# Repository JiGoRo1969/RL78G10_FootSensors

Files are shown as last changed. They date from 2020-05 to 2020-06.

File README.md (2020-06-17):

# FootSensors with RL78/G10 software library (Rev.20200416)

This is a project to use Force Sensing Registors with RL78/G10
included with CS+ environment setting files provided by Renesas Electronics Corp.
So you can easily modify and add this codes with CS+ on Windows PC.
  
Let's enjoy it !

## Information for target board

RL78/G10 board "AE-R5F10Y47ASP" is provided by Akizukidenshi in Japan.
  
JPN : http://akizukidenshi.com/catalog/g/gK-09035/

## Installation

Import this project into CS+.

## Usage

The protocol stack is defined with an ICS3.5 provided by KONDO Kagaku.
ICS3.5 uses "Data=8bit, Stop=1bit, Parity=EVEN, baudrate=1.5Mbps."
You will get 4 sensor unit data when master MCU/MPU send 4 bytes data as follows :
|Command|SC|Address|Length|
|---|--|---|---|
|0xA0+ID|0x7F|0(fiexed)|4(fiexed)|
  
ID is defined as D_MY_ID in "cg_src/r_cg_userdefine.h".

## Current Support Peripherals

|Function Name | Pin Name | notes |
|:---|:---:|:---|
|Analog Input |P02/ANI1 | connecting to one of Force Sensing Registor with pulled up to 3.3V | 
|Analog Input |P03/ANI2 | connecting to one of Force Sensing Registor with pulled up to 3.3V | 
|Analog Input |P04/ANI3 | connecting to one of Force Sensing Registor with pulled up to 3.3V | 
|Analog Input |P05/ANI4 | connecting to one of Force Sensing Registor with pulled up to 3.3V | 
|UART I/F |P00/TxD0 | connecting to RxD of master MCU/MPU | 
|UART I/F |P01/RxD0 | connecting to TxD of master MCU/MPU | 
|X'tal |X1,X2 | mounted on board |
|OCD Debugger I/F |RESET, TOOL0 | connecting to DEBUGGER |
|Non Connections |P06, P07, P41 | |
  
You can refer CAD data with Eagle(.brd and .sch) to understand the circuit.
  
|File Name | purpose |
|:---:|:---:|
|RL78G10_FOOT_A2.brd| PCB pattern data for pressure sensors with R5F10Y47ASP|
|RL78G10_FOOT_A2.sch| circuit data |
|--------|-------|
|RL78G10_E1.brd| PCB pattern data connecting to E1/E2/E2Lite |
|RL78G10_E1.sch| circuit data |

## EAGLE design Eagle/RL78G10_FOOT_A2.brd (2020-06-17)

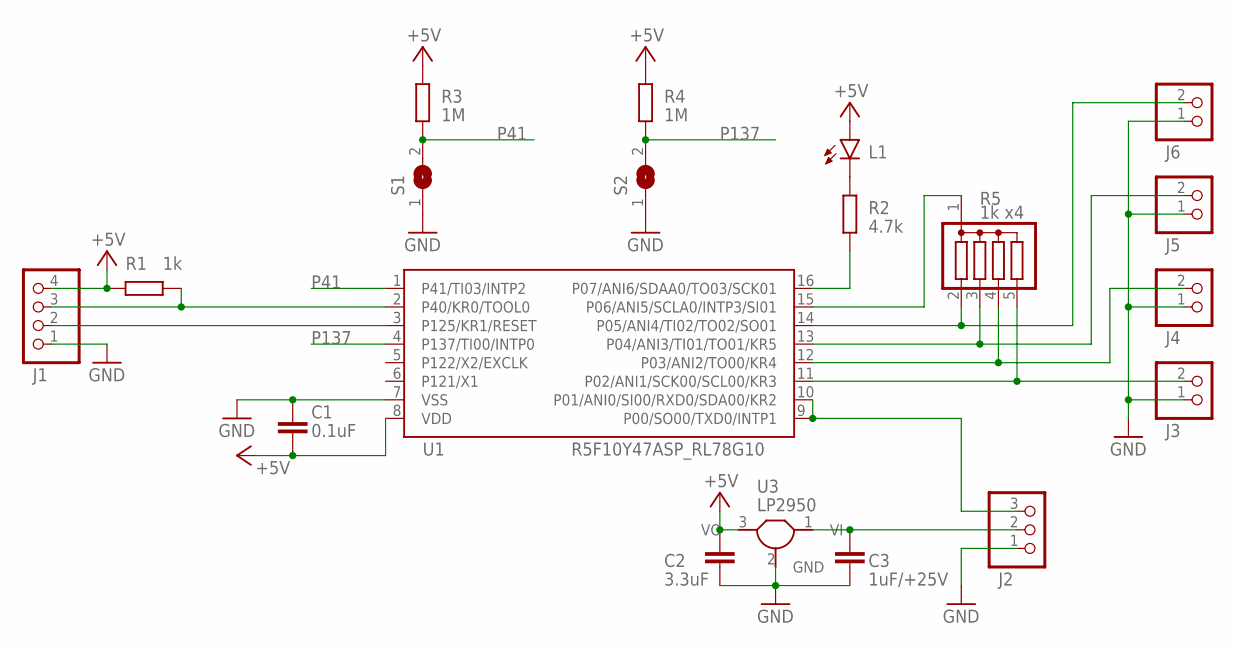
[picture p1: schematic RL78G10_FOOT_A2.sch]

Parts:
C1: 0.1uF; C0603
C2: 3.3uF; C0805
C3: 1uF/+25V; C0805
J1: PINHD_1X4; PINHD_1X04
J2: PINHD_1X3; PINHD_1X03
J3, J4, J5, J6: PINHD_1X2; PINHD_1X02
L1: LEDSML0603; SML0603
R1: 1k; R0603
R2: 4.7k; R0603
R3, R4: 1M; R0603
R5: 1k x4; SIL5
S1, S2: SJ-OMINI; SJ-O
U1: R5F10Y47ASP_RL78G10; SSOP16
U3: LP2950; TO92-

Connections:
+5V: C1.2, C2.1, J1.4, L1.A, R1.1, R3.1, R4.1, U1.8 (VDD), U3.3 (VO)
+V: C3.1, J2.2, U3.1 (VI)
ANI1: J3.2, R5.5, U1.11 (P02/ANI1/SCK00/SCL00/KR3)
ANI2: J4.2, R5.4, U1.12 (P03/ANI2/TO00/KR4)
ANI3: J5.2, R5.3, U1.13 (P04/ANI3/TI01/TO01/KR5)
ANI4: J6.2, R5.2, U1.14 (P05/ANI4/TI02/TO02/SO01)
GND: C1.1, C2.2, C3.2, J1.1, J2.1, J3.1, J4.1, J5.1, J6.1, S1.1, S2.1, U1.7 (VSS), U3.2 (GND)
LED: L1.C, R2.1
P06: R5.1, U1.15 (P06/ANI5/SCLA0/INTP3/SI01)
P41: R3.2, S1.2, U1.1 (P41/TI03/INTP2)
P137: R4.2, S2.2, U1.4 (P137/TI00/INTP0)
RESET: J1.2, U1.3 (P125/KR1/RESET)
SIG: J2.3, U1.9 (P00/SO00/TXD0/INTP1), U1.10 (P01/ANI0/SI00/RXD0/SDA00/KR2)
TO03: R2.2, U1.16 (P07/ANI6/SDAA0/TO03/SCK01)
TOOL0: J1.3, R1.2, U1.2 (P40/KR0/TOOL0)

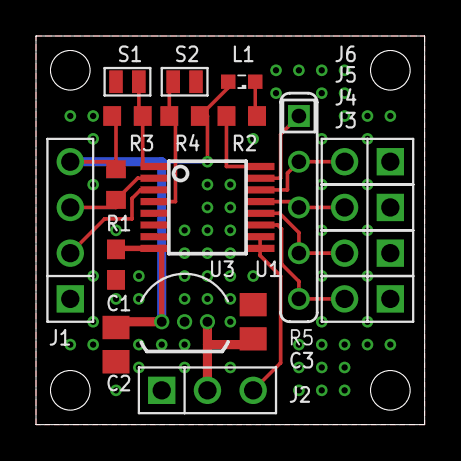
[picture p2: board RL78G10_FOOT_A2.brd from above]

Board: 2 copper layers, 21.6 x 21.6 mm, 19 parts (0 on the bottom side), 15 nets.

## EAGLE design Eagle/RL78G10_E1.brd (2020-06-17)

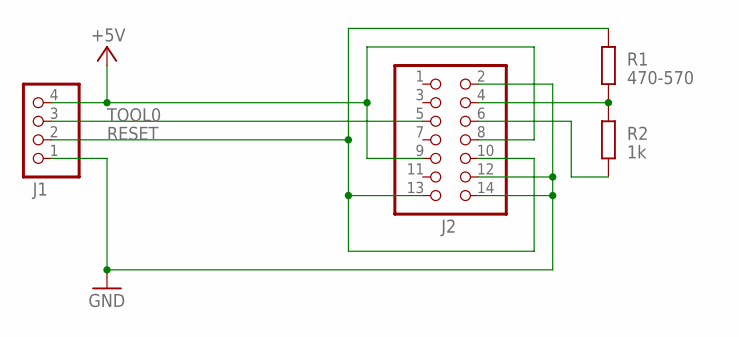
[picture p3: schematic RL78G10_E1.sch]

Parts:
J1: PINHD_1X4; PINHD_1X04
J2: PINHD_2X07
R1: 470-570; R0603
R2: 1k; R0603

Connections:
+5V: J1.4, J2.8, J2.9
GND: J1.1, J2.2, J2.12, J2.14
P4: J2.4, R1.1, R2.2
P6: J2.6, R2.1
RESET: J1.2, J2.10, J2.13, R1.2
TOOL0: J1.3, J2.5

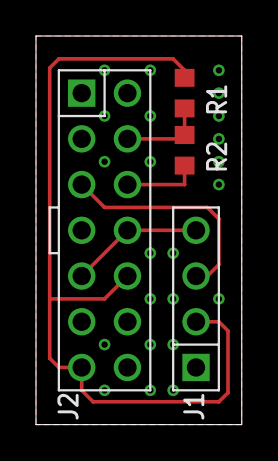
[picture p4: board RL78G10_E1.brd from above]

Board: 2 copper layers, 11.4 x 21.6 mm, 4 parts (0 on the bottom side), 6 nets.

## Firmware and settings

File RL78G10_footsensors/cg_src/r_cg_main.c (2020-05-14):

/*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
* Copyright (C) 2012, 2019 Renesas Electronics Corporation. All rights reserved.
***********************************************************************************************************************/

/***********************************************************************************************************************
* File Name    : r_cg_main.c
* Version      : Code Generator for RL78/G10 V1.05.03.02 [20 Nov 2019]
* Device(s)    : R5F10Y47
* Tool-Chain   : CCRL
* Description  : This file implements main function.
* Creation Date: 2020/04/03
***********************************************************************************************************************/

/***********************************************************************************************************************
Includes
***********************************************************************************************************************/
#include "r_cg_macrodriver.h"
#include "r_cg_cgc.h"
#include "r_cg_port.h"
#include "r_cg_adc.h"
#include "r_cg_sau.h"
/* Start user code for include. Do not edit comment generated here */
/* End user code. Do not edit comment generated here */
#include "r_cg_userdefine.h"

/***********************************************************************************************************************
Pragma directive
***********************************************************************************************************************/
/* Start user code for pragma. Do not edit comment generated here */
/* End user code. Do not edit comment generated here */

/***********************************************************************************************************************
Global variables and functions
***********************************************************************************************************************/
/* Start user code for global. Do not edit comment generated here */
static uint8_t		s_txbuf[32];
static uint16_t		s_adcval[4];

//#define 	D_USE_DEMO_DISPLAY_CONSOLE

/* End user code. Do not edit comment generated here */

static void R_MAIN_UserInit(void);
/***********************************************************************************************************************
* Function Name: main
* Description  : This function implements main function.
* Arguments    : None
* Return Value : None
***********************************************************************************************************************/
void main(void)
{
    R_MAIN_UserInit();
    /* Start user code. Do not edit comment generated here */
#ifdef	D_USE_DEMO_DISPLAY_CONSOLE
	POM0	= 0;
#endif	// D_USE_DEMO_DISPLAY_CONSOLE
	R_UART0_RX_Start();
	while(1)
	{
#ifndef	D_USE_DEMO_DISPLAY_CONSOLE
		__halt();
		if(0 == g_flg_rxfin)
		{
			ADMK		= 1U;		/* disable INTAD interrupt */
			s_adcval[0] = 16383U - g_adc_data[0];
			s_adcval[1] = 16383U - g_adc_data[1];
			s_adcval[2] = 16383U - g_adc_data[2];
			s_adcval[3] = 16383U - g_adc_data[3];
			ADMK		= 0U;		/* enable INTAD interrupt */
			continue;
		}
		g_flg_rxfin = 0;
		//
		s_txbuf[ 4]	= (s_adcval[0]     ) & 0x7F;
		s_txbuf[ 5]	= (s_adcval[0] >> 7) & 0x7F;
		s_txbuf[ 6]	= (s_adcval[1]     ) & 0x7F;
		s_txbuf[ 7]	= (s_adcval[1] >> 7) & 0x7F;
		s_txbuf[ 8]	= (s_adcval[2]     ) & 0x7F;
		s_txbuf[ 9]	= (s_adcval[2] >> 7) & 0x7F;
		s_txbuf[10]	= (s_adcval[3]     ) & 0x7F;
		s_txbuf[11]	= (s_adcval[3] >> 7) & 0x7F;
		//
		R_UART0_RX_Start();
		//
		R_UART0_Send(s_txbuf, 12);
		while(0 == g_flg_txfin);
		g_flg_txfin = 0;
#else	// D_USE_DEMO_DISPLAY_CONSOLE
		const uint8_t		s_hex2chr[] = "0123456789ABCDEF";

		ADMK		= 1U;		/* disable INTAD interrupt */
		s_txbuf[ 0]	= s_hex2chr[(g_adc_data[0] >>12) & 15];
		s_txbuf[ 1]	= s_hex2chr[(g_adc_data[0] >> 8) & 15];
		s_txbuf[ 2]	= s_hex2chr[(g_adc_data[0] >> 4) & 15];
		s_txbuf[ 3]	= s_hex2chr[(g_adc_data[0]     ) & 15];
		s_txbuf[ 4] = ',';
		s_txbuf[ 5]	= s_hex2chr[(g_adc_data[1] >>12) & 15];
		s_txbuf[ 6]	= s_hex2chr[(g_adc_data[1] >> 8) & 15];
		s_txbuf[ 7]	= s_hex2chr[(g_adc_data[1] >> 4) & 15];
		s_txbuf[ 8]	= s_hex2chr[(g_adc_data[1]     ) & 15];
		s_txbuf[ 9] = ',';
		s_txbuf[10]	= s_hex2chr[(g_adc_data[2] >>12) & 15];
		s_txbuf[11]	= s_hex2chr[(g_adc_data[2] >> 8) & 15];
		s_txbuf[12]	= s_hex2chr[(g_adc_data[2] >> 4) & 15];
		s_txbuf[13]	= s_hex2chr[(g_adc_data[2]     ) & 15];
		s_txbuf[14] = ',';
		s_txbuf[15]	= s_hex2chr[(g_adc_data[3] >>12) & 15];
		s_txbuf[16]	= s_hex2chr[(g_adc_data[3] >> 8) & 15];
		s_txbuf[17]	= s_hex2chr[(g_adc_data[3] >> 4) & 15];
		s_txbuf[18]	= s_hex2chr[(g_adc_data[3]     ) & 15];
		s_txbuf[19] = '\n';
		ADMK		= 0U;		/* enable INTAD interrupt */
		R_UART0_Send(s_txbuf, 20);
		while(0 == g_flg_txfin);
		g_flg_txfin = 0;
#endif	// D_USE_DEMO_DISPLAY_CONSOLE
	}

    /* End user code. Do not edit comment generated here */
}
/***********************************************************************************************************************
* Function Name: R_MAIN_UserInit
* Description  : This function adds user code before implementing main function.
* Arguments    : None
* Return Value : None
***********************************************************************************************************************/
static void R_MAIN_UserInit(void)
{
    /* Start user code. Do not edit comment generated here */
	EI();
	//
	g_flg_rxfin	= 0;
	g_flg_txfin = 0;
	s_txbuf[0]	= D_ISC35_RCMD | D_MY_ID;
	s_txbuf[1]	= D_ISC35_SC;
	s_txbuf[2]	= 0;
	s_txbuf[3]	= 4;
	//
	R_UART0_TX_Start();
	R_ADC_Set_OperationOn();
	R_ADC_Start();

    /* End user code. Do not edit comment generated here */
}

/* Start user code for adding. Do not edit comment generated here */
/* End user code. Do not edit comment generated here */

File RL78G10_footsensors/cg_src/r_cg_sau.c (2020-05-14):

/*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
* Copyright (C) 2012, 2019 Renesas Electronics Corporation. All rights reserved.
***********************************************************************************************************************/

/***********************************************************************************************************************
* File Name    : r_cg_sau.c
* Version      : Code Generator for RL78/G10 V1.05.03.02 [20 Nov 2019]
* Device(s)    : R5F10Y47
* Tool-Chain   : CCRL
* Description  : This file implements device driver for SAU module.
* Creation Date: 2020/04/03
***********************************************************************************************************************/

/***********************************************************************************************************************
Includes
***********************************************************************************************************************/
#include "r_cg_macrodriver.h"
#include "r_cg_sau.h"
/* Start user code for include. Do not edit comment generated here */
/* End user code. Do not edit comment generated here */
#include "r_cg_userdefine.h"

/***********************************************************************************************************************
Pragma directive
***********************************************************************************************************************/
/* Start user code for pragma. Do not edit comment generated here */
/* End user code. Do not edit comment generated here */

/***********************************************************************************************************************
Global variables and functions
***********************************************************************************************************************/
volatile uint8_t * gp_uart0_tx_address;        /* uart0 transmit buffer address */
volatile uint16_t  g_uart0_tx_count;           /* uart0 transmit data number */
volatile uint8_t * gp_uart0_rx_address;        /* uart0 receive buffer address */
volatile uint16_t  g_uart0_rx_count;           /* uart0 receive data number */
volatile uint16_t  g_uart0_rx_length;          /* uart0 receive data length */
/* Start user code for global. Do not edit comment generated here */
/* End user code. Do not edit comment generated here */

/***********************************************************************************************************************
* Function Name: R_SAU0_Create
* Description  : This function initializes the SAU0 module.
* Arguments    : None
* Return Value : None
***********************************************************************************************************************/
void R_SAU0_Create(void)
{
    SAU0EN = 1U;    /* supply SAU0 clock */
    NOP();
    NOP();
    NOP();
    NOP();
    SPS0 = _00_SAU_CK00_FCLK_0 | _00_SAU_CK01_FCLK_0;
    R_UART0_Create();
}
/***********************************************************************************************************************
* Function Name: R_UART0_Create
* Description  : This function initializes the UART0 module.
* Arguments    : None
* Return Value : None
***********************************************************************************************************************/
void R_UART0_Create(void)
{
    ST0 |= _02_SAU_CH1_STOP_TRG_ON | _01_SAU_CH0_STOP_TRG_ON;    /* disable UART0 receive and transmit */
    STMK0 = 1U;    /* disable INTST0 interrupt */
    STIF0 = 0U;    /* clear INTST0 interrupt flag */
    SRMK0 = 1U;    /* disable INTSR0 interrupt */
    SRIF0 = 0U;    /* clear INTSR0 interrupt flag */
    SREMK0 = 1U;   /* disable INTSRE0 interrupt */
    SREIF0 = 0U;   /* clear INTSRE0 interrupt flag */
    /* Set INTST0 low priority */
    STPR10 = 1U;
    STPR00 = 1U;
    /* Set INTSR0 level2 priority */
    SRPR10 = 1U;
    SRPR00 = 0U;
    SMR00L = _20_SAU_SMRMN_INITIALVALUE | _02_SAU_MODE_UART | _01_SAU_BUFFER_EMPTY;
    SMR00H = _00_SAU_CLOCK_SELECT_CK00 | _00_SAU_TRIGGER_SOFTWARE;
    SCR00L = _80_SAU_LSB | _10_SAU_STOP_1 | _07_SAU_LENGTH_8;
    SCR00H = _80_SAU_TRANSMISSION | _00_SAU_INTSRE_MASK | _02_SAU_PARITY_EVEN;
    SDR00H = _0E_UART0_TRANSMIT_DIVISOR;
    NFEN0 |= _01_SAU_RXD0_FILTER_ON;
    SIR01 = _04_SAU_SIRMN_FECTMN | _02_SAU_SIRMN_PECTMN | _01_SAU_SIRMN_OVCTMN;    /* clear error flag */
    SMR01L = _20_SAU_SMRMN_INITIALVALUE | _00_SAU_EDGE_FALL | _02_SAU_MODE_UART | _00_SAU_TRANSFER_END;
    SMR01H = _00_SAU_CLOCK_SELECT_CK00 | _01_SAU_TRIGGER_RXD;
    SCR01L = _80_SAU_LSB | _10_SAU_STOP_1 | _07_SAU_LENGTH_8;
    SCR01H = _40_SAU_RECEPTION | _00_SAU_INTSRE_MASK | _02_SAU_PARITY_EVEN;
    SDR01H = _0E_UART0_RECEIVE_DIVISOR;
    SO0 |= _01_SAU_CH0_DATA_OUTPUT_1;
    SOL0 |= _00_SAU_CHANNEL0_NORMAL;    /* output level normal */
    SOE0 |= _01_SAU_CH0_OUTPUT_ENABLE;    /* enable UART0 output */
    /* Set RXD0 pin */
    PMC0 &= 0xFDU;
    PM0 |= 0x02U;
    /* Set TXD0 pin */
    P0 |= 0x01U;
    PM0 &= 0xFEU;
}
/***********************************************************************************************************************
* Function Name: R_UART0_Start
* Description  : This function starts the UART0 module operation.
* Arguments    : None
* Return Value : None
***********************************************************************************************************************/
void R_UART0_Start(void)
{
    SO0 |= _01_SAU_CH0_DATA_OUTPUT_1;    /* output level normal */
    SOE0 |= _01_SAU_CH0_OUTPUT_ENABLE;    /* enable UART0 output */
    SS0 |= _02_SAU_CH1_START_TRG_ON | _01_SAU_CH0_START_TRG_ON;    /* enable UART0 receive and transmit */
    STIF0 = 0U;    /* clear INTST0 interrupt flag */   
    SRIF0 = 0U;    /* clear INTSR0 interrupt flag */
    STMK0 = 0U;    /* enable INTST0 interrupt */
    SRMK0 = 0U;    /* enable INTSR0 interrupt */
}
/***********************************************************************************************************************
* Function Name: R_UART0_Stop
* Description  : This function stops the UART0 module operation.
* Arguments    : None
* Return Value : None
***********************************************************************************************************************/
void R_UART0_Stop(void)
{
    STMK0 = 1U;    /* disable INTST0 interrupt */
    SRMK0 = 1U;    /* disable INTSR0 interrupt */
    ST0 |= _02_SAU_CH1_STOP_TRG_ON | _01_SAU_CH0_STOP_TRG_ON;    /* disable UART0 receive and transmit */
    SOE0 &= (uint8_t)~_01_SAU_CH0_OUTPUT_ENABLE;    /* disable UART0 output */
    STIF0 = 0U;    /* clear INTST0 interrupt flag */
    SRIF0 = 0U;    /* clear INTSR0 interrupt flag */
}
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
